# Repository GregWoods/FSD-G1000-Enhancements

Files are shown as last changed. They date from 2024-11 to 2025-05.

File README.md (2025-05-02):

# FSD G1000 Enhancements

This is a collection of my own personal enhancements to the [FlightSimDiy](https://flightsimdiy.com/) G1000 module. https://discord.com/channels/769685829744197703/769689559499800589

It is a great design incorporating PCBs and well 3D printed files.

I have seen a lot of 95% finished designs with missing knobs, and I myself had trouble with the hole dia and length when using a 3rd party resin printing service, and after printing them myself using FDM.

To remedy this, I created my own parametric knobs. 
All designs are 100% my own, created from scratch, based on measurements taken from the FSD designs and the rotary encoders I have.

## WARNING: Using these files requires knowledge of FreeCAD

* FreeCAD is unforgiving!
* I have provided tips here, but you will need to figure out how to do those things yourself. I would love to write a tutorial, but it takes time.

## FreeCAD Tips:

* The knurling pattern on the knobs makes FreeCAD insanely slow at re-rendering. I strongly suggest you turn on "Skip Recomputes" on the document, and recompute manually
* Size adjustments are done by modifying the FreeCAD spreadsheet values and "recomputing" the body
* To create an STL file, you will first need to create a mesh from the solid body, then export the mesh as an STL

## 3D Printing Tips

* Callibrate your printer... in particular the flow rate / extrusion rate. My Ender 3 S1 Pro needed 94% flow rate, and this improved hole sizing a lot.
* [Revised Advice] Use the slicer's Hole Enlargement setting wth the supplied STL files instead of messing with FreeCAD
* Use a 0.2mm nozzle for a nicer result - as long as it doesn't clog
* Use a small layer height
* [IMPORTANT] Print on a RAFT - aprticularly for the knobs... this prevents the elephants foot effect and massively reduces the amount of deburring you will need to do to make the knobs fit

## My ToDo

* Create a tutorial
* Test using FreeCAD's Lattice2 Workbench for the knurling... to see if performance is improved

## Notes on the Fit of the Knobs

When printed on a Ender 3 S1 Pro with Elegoo filament.

Originally I was adjusting the holes in the parametric model, but due to FreeCad being mind-numbingly slow when using Multitransform for the knurling, I have instead experimented with setting the hole to the exact size of the shaft, and adjust the fit with the slicers Hole Enlargement setting. 

My advice is to print these one at a time, noting carefully the settings used to get the perfect fit.

### Common Settings

* No supports
* Raft, with air gap equal to layer height
* Nozzle size 0.4mm (I kept clogging my 0.2 nozzles)

### Holes Sizes and Hole Compensation Setting

| Model | Actual Shaft Dia | Parametric Hole Dia | Printer Settings | Fit Notes |
| :--- | ---: | ---: | :--- | :--- |
| inner_knob | 3.50mm | 3.63mm | 0.0mm Hole Enlargement | Tight fit. but no trimming required |
| inner_knob | 3.50mm | 3.50mm | 0.13mm Hole Enlargement | Good fit, not as tight as above |
| inner_knob | 3.50mm | 3.50mm | 0.12mm Hole Enlargement | Same as above |
| single_navcom | 5.95mm | 6.16mm | 0.0mm Hole Enlargement | Good fit, but differnt filament, & unknown print settings |
| single_navcom | 5.95mm | 5.95mm | 0.2mm Hole Enlargement | An initial "snap" moment, then too big  |
| single_navcom | 5.95mm | 5.95mm | 0.12mm Hole Enlargement | Good fit. Needed a little trimming (missing chamfer) |
| inner_tri | 3.50mm | 3.60mm | 0.00mm Hole Enlargement | Good fit, but differnt filament, & unknown print settings |
| inner_tri | 3.50mm | 3.50mm | 0.12mm Hole Enlargement | Awaiting result |
| | | | 0.0mm Hole Enlargement | |
| | | | 0.0mm Hole Enlargement | |
| | | | 0.0mm Hole Enlargement | |

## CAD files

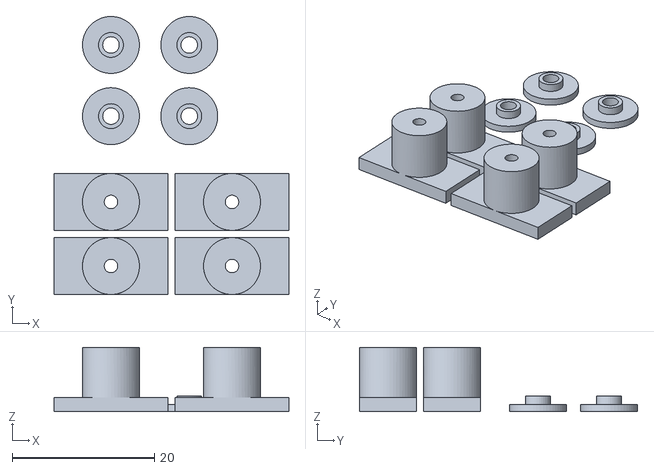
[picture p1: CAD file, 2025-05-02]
Display_PCB_Standoffs v1.stl
33.0 x 39.0 x 9.00

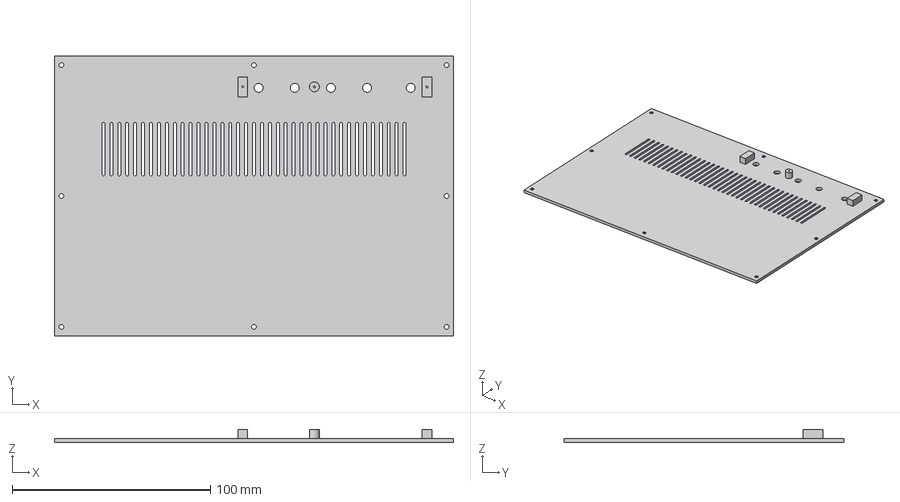
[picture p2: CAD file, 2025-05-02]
G1000 back panel with monitor buttons.step
201.4 x 141.2 x 6.50 mm

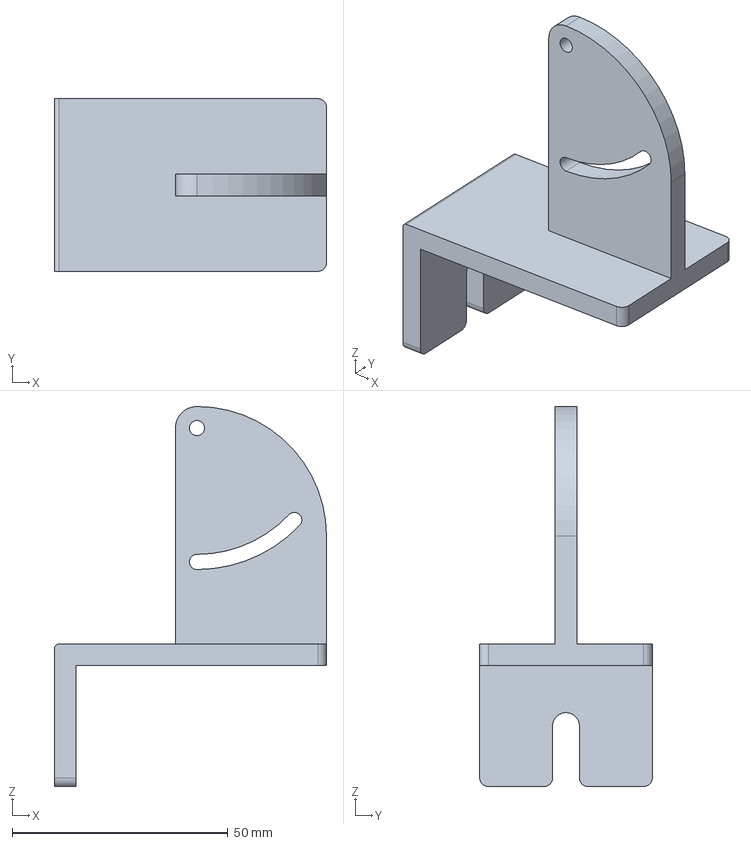
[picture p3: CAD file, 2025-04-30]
G1000_desk_mount_foot.FCStd
63.0 x 40.0 x 88.0 mm

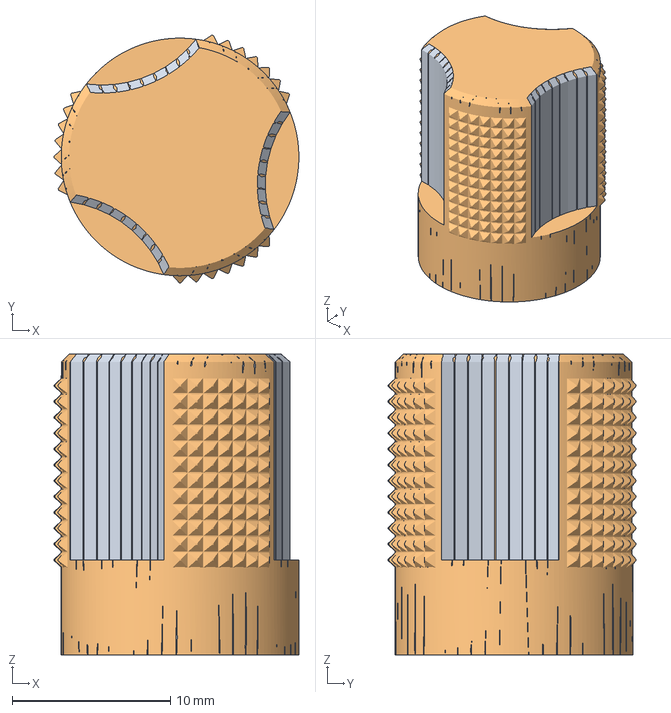
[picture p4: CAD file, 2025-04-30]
G1000_single_hdg.FCStd
15.5 x 15.6 x 19.0 mm
G1000_single_hdg

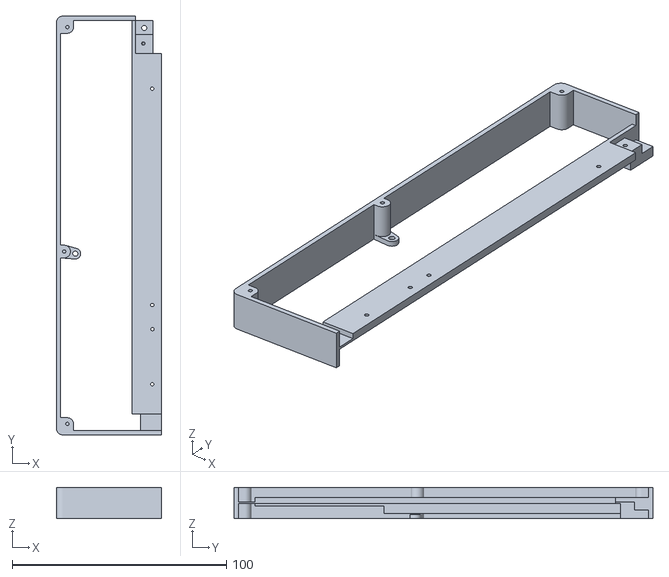
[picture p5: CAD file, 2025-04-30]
G1000_left_frame_thicker_lcd.stl
49.2 x 195.6 x 14.6

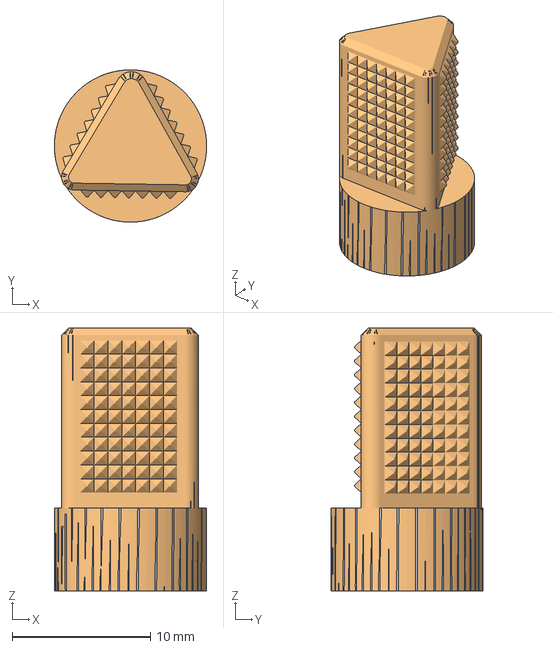
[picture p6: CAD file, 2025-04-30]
G1000_inner_knob_tri.FCStd
11.0 x 11.0 x 19.0 mm
Main Body
G1000_inner_knob_tri

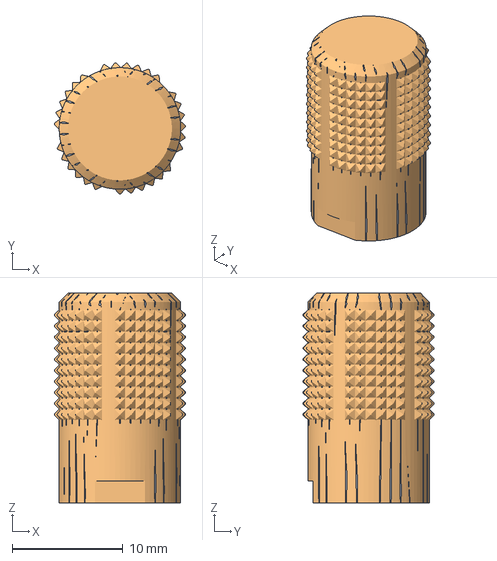
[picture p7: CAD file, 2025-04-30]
G1000_inner_knob_std.FCStd
11.9 x 11.9 x 19.0 mm
Knob
G1000_inner_knob_std

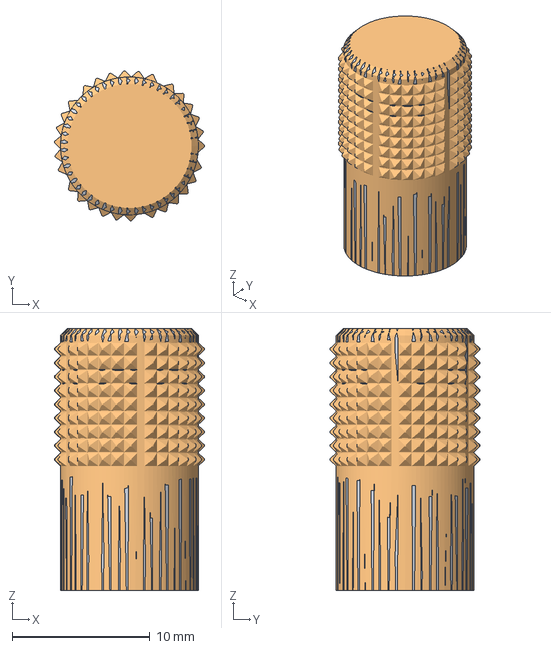
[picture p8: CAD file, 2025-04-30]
G1000_single_navcom.FCStd
10.9 x 10.9 x 19.0 mm
G1000_single_navcom

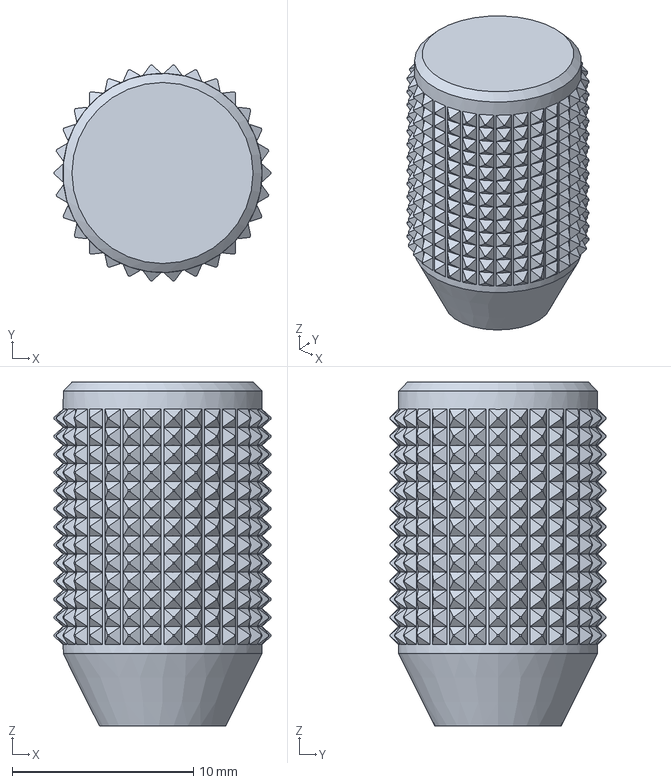
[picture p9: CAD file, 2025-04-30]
G1000_panzoom.FCStd
12.0 x 11.9 x 19.0 mm

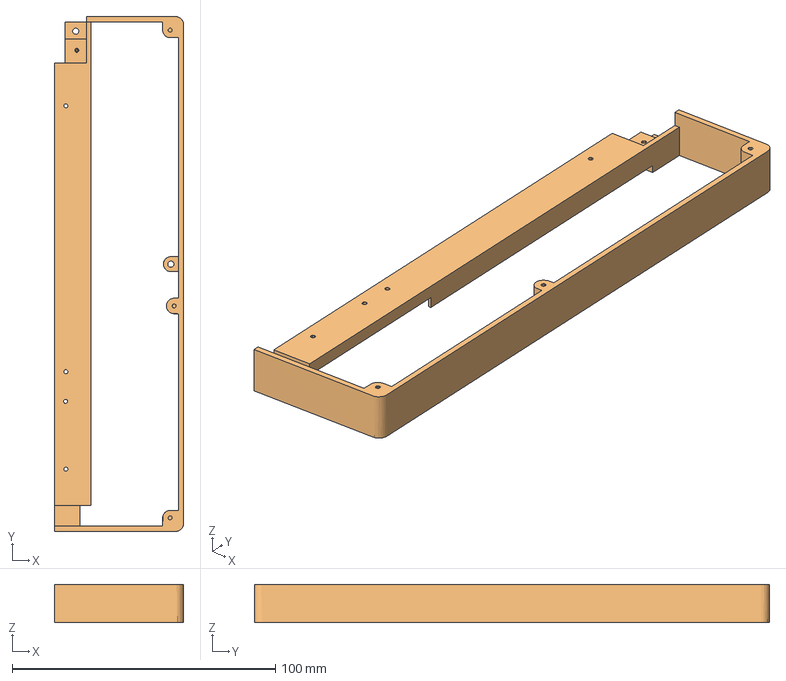
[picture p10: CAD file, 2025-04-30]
G1000_right_frame_thicker_LCD.FCStd
49.2 x 195.6 x 14.6 mm
Cut001 (Meshed)

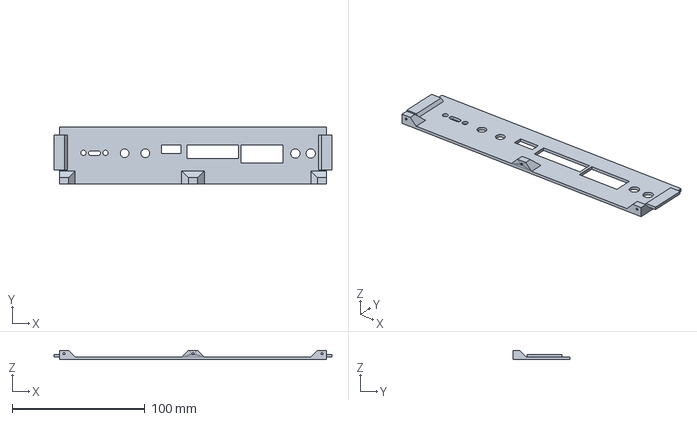
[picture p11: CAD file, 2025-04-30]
G1000_top_panel_with_ports.FCStd
209.4 x 43.0 x 7.00 mm

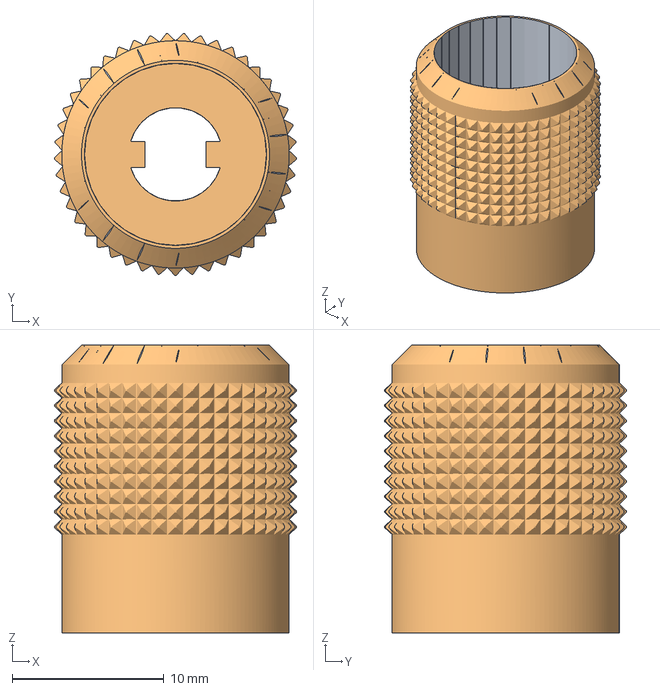
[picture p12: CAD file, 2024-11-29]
G1000_outer.FCStd
16.0 x 16.0 x 19.0 mm
G1000_outer_GWL

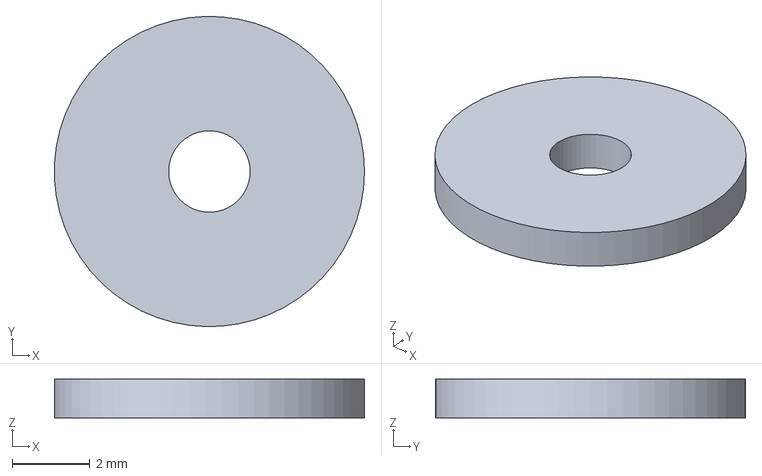
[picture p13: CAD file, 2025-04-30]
washers.FCStd
7.99 x 8.00 x 1.00 mm

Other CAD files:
G1000 back panel with monitor buttons.3mf
G1000_desk_mount_foot.stl
G1000_inner_knob_std.stl
G1000_inner_knob_tri.stl
G1000_outer.stl
G1000_panzoom.stl
G1000_right_frame_thicker_LCD.stl
G1000_single_hdg.stl
G1000_single_navcom.stl
G1000_top_panel_with_ports.stl
washers.stl

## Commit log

2024-11-29 my initial, with MIT licence
    [G1000_inner_knob_std.FCStd, G1000_inner_knob_std.stl, G1000_inner_knob_tri.FCStd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]
2024-12-01 panzoom removed chamfer on shaft. It gave too much panning movement, resulting in accidental "clicks" of the button
2025-04-30 More 3D print improvements
    [Display_PCB_Standoffs v1.stl, G1000 back panel with monitor buttons.3mf, G1000 back panel with monitor buttons.step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]
2025-05-02 whitespace only after a git install
    [Display_PCB_Standoffs v1.stl, G1000 back panel with monitor buttons.step]
